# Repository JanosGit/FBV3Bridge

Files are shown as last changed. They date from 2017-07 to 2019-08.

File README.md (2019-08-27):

# FBV3Bridge
PJRC Teensy 3.2 based device to interface a Line 6 FBV3 to a USB-Serial Port to access its functionality through Max for Live or Max/MSP

Inspired by some other projects out there ([this one by rasmartins](https://github.com/rasmartins/fbv2kpa) and [this one by wrbi](https://github.com/wrbi/FBV2MIDI)), that have successfully interfaced the older FBV-range boards, the goal of this project is to make use of the extended functionality of the FBV3 Board - most of all the RGB-LEDs.

Within this project, I'm responsible of designing the hardware that acts as bridge between your PC or Mac and ther Line 6 FBV3 Board. Most of the reverse engineering of the communication protocol and the design of an upcoming Max for Live device that lets you control Ableton Live with an FBV3 board is done by [Soundmanufacture](http://soundmanufacture.net/index.html).

## The Max Patcher

You'll find a first proof-of-cocept Max patcher that allows setting the colours of nearly all Button LEDs as well as reading the state of the buttons and the expression pedal in the "Max" subfolder of this repository.

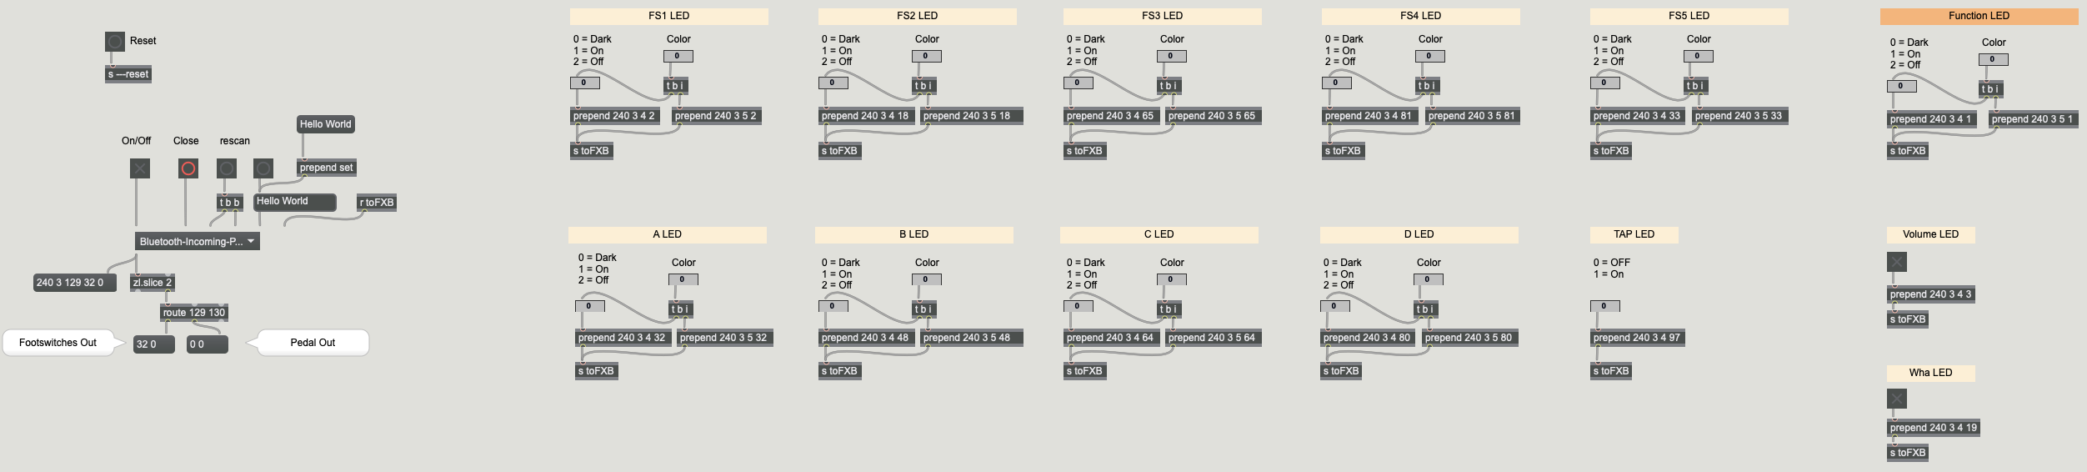
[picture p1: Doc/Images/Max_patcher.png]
Max screenshot

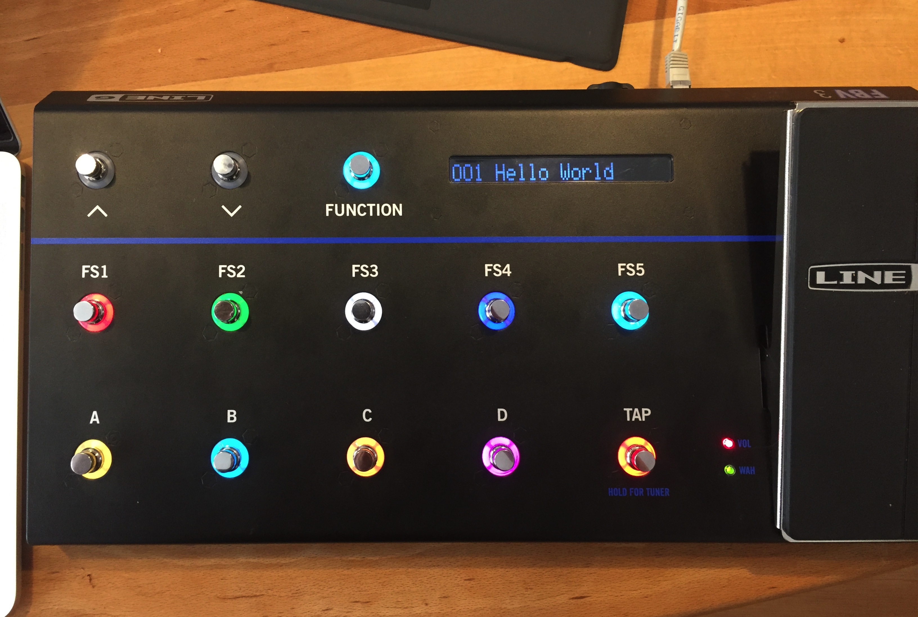
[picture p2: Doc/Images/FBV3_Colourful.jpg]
FBV3 with colourful buttons set by the patch


## The hardware

Our first hardware prototype consists of a small PCB, interfacing two RS485 over RJ45 connections used by Line 6 to the Teensy on the one side and supplying an USB connection to connect with your computer on the other side. The two RJ45 connections were added to make it possible to attach the device between the floorboard and an original Line 6 amp and reord data traffic to make protocol reverse engineering possible. In a second mode of operation the device just initializes the FBV3 board as the amp would do and then acts as a transparent RS485 to serial bridge. 

The initial plan was to power the board via USB, however it seems that not all USB port supply enough current, so we had to modify the design to power it with an external 9V power adapter.

### Next hardware generation

After being successful in reverse-engineering the protocol we are currently planing a second hardware generation. Features of this new hardware should be

- More compact design, all components including the MCU and a proper power suply circuit on one board instead of plugging a Teensy onto the board
- Professional manufactured PCB instead of the home-made design of the prototype, making solering SMT components much easier
- 3D printed housing to make it finally suitable for stage-use
- Fix some minor errors in the schematics

News regarding the new designs will be posted here as soon as available

### Impressions of the prototype

Here are some pictures of the first version of the prototype that was still USB-Bus powered. You'll find the schematics in the "Hardware" subfolder of this repo.

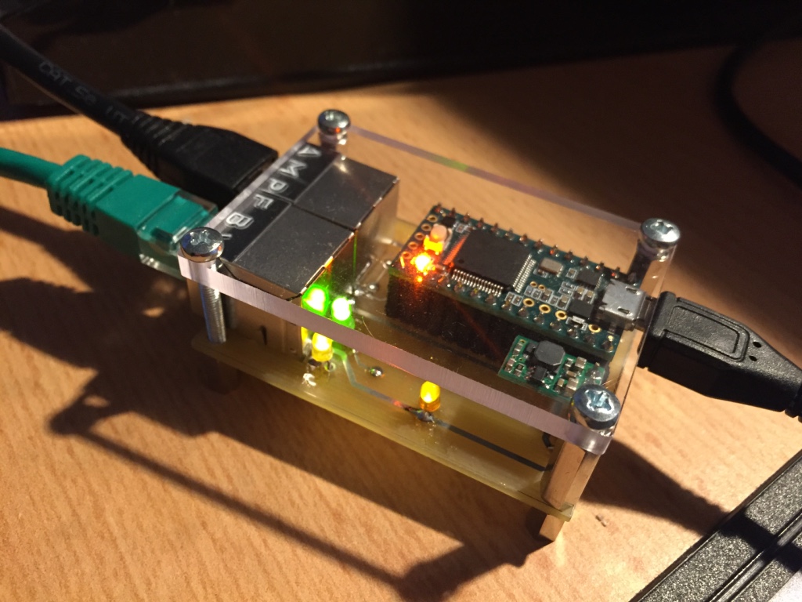
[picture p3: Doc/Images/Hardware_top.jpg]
Hardware top view


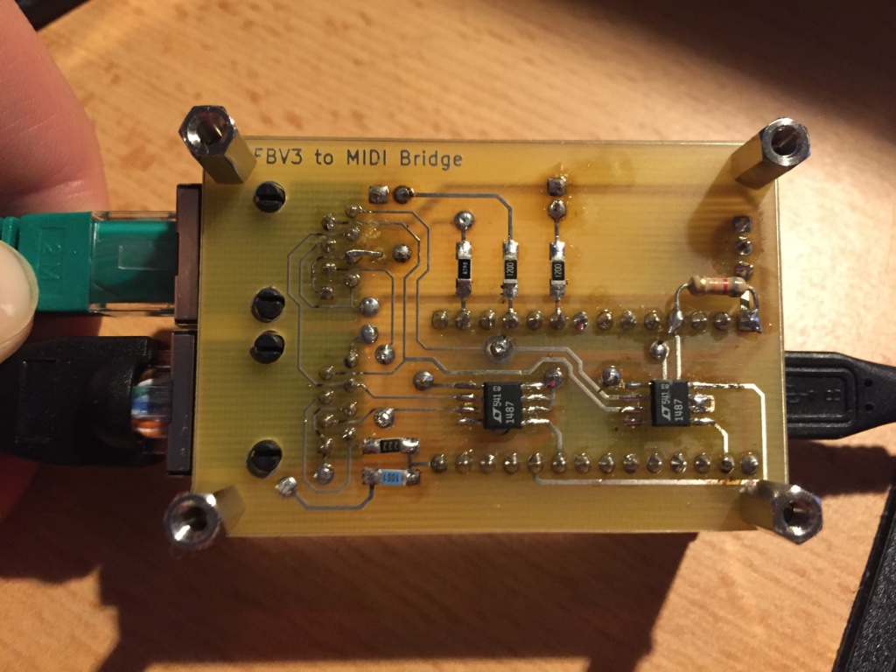
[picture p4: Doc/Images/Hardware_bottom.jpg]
Hardware bottom view


### The software modes of the prototype
As said above, the software for the Teensy has two modes of operation: If both an amp and an FBV3 Board are plugged in, it logs the communication between the two endpoints and prints it in human-readable form to the USB-Serial output. If no amp is plugged in, it sends the same initialization-sequence an amp would send to the FBV3 board and redirects the in/out data streams byte-transparent to the USB-Serial port afterwards.

With the help of the first mode, the protocol of the FBV3 could be reverse-engineered.
Here you see a screenshot of the serial communication logged while the device was in the first mode.

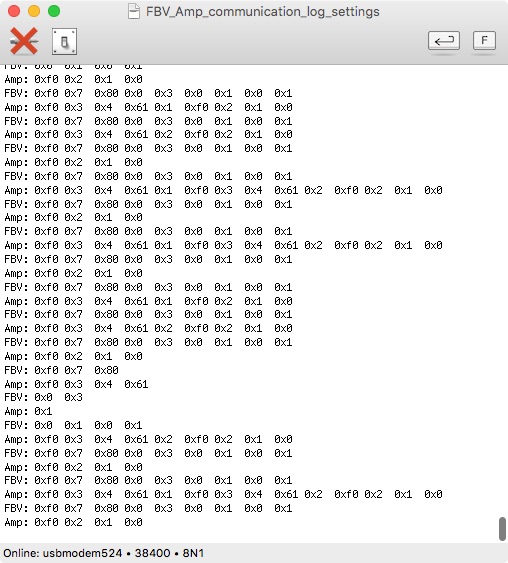
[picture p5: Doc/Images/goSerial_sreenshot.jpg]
goSerial screenshot goSerial Screenshot


In this mode, the amp and the FBV3 behave just like there wouldn't be anything more than a cable connecting them.
In the second mode, the Teensy sends an initialization sequence (actually, completely the same sequence as the Line 6 Spider Amp I had here sent - I just changed the content sent to the LCD display). So it boots up like this:

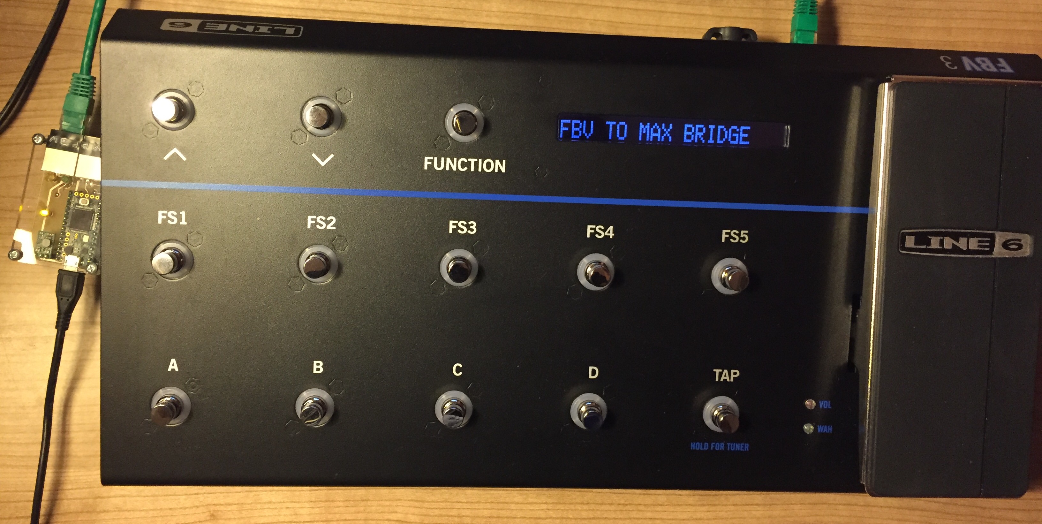
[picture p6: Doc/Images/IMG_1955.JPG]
Teensy initialized the FBV3


The current software is based on the Teensyduino environment and can be found in the "Software/FBV3Bridge" subfolder of this repository

## Known facts about the protocol

Each valid message seems to have the following structure:

| Start byte | Number of bytes following | Command type | Parameters |
|:---:|---|---|---|
| 0xF0 | Counted without this byte --> Message Length - 2 | e.g. 0x04 for Button LEDs | e.g. Button Number, On/Off |

These messages could already be identified:
### Switching Button LEDs

| 0xF0 | 0x03 | 0x04 | Button Number | 0x01 for "On", 0x00 for "Dark" (or "Off" if LED red), 0x02 for "Off" |
|:----:|:----:|:----:|:---:|:---:|

### Setting Button LED Colours

| 0xF0 | 0x03 | 0x05 | Button Number | A value betweem 0x00 and 0x09 for 9 different colours |
|:----:|:----:|:----:|:---:|:---:|

### First three display characters (-> The preset number)
Note: Although Line 6 uses this for the preset number, all possible ascii characters seem to be working here

| 0xF0 | 0x05 | 0x08 | 0x20 | character 1 | character 2 | character 3 |
|:----:|:----:|:----:|:----:|:---:|:---:|:---:|

### The remaining display text
Note: It seems to be unavoidable that there is a whitespace between the first three characters of the preset nubmer and the remainig display text

| 0xF0 | text length + 3 | 0x10 | 0x00 | 0x01 | the text as ascii string |
|:----:|:---:|:----:|:----:|:----:|:---:|

Note that

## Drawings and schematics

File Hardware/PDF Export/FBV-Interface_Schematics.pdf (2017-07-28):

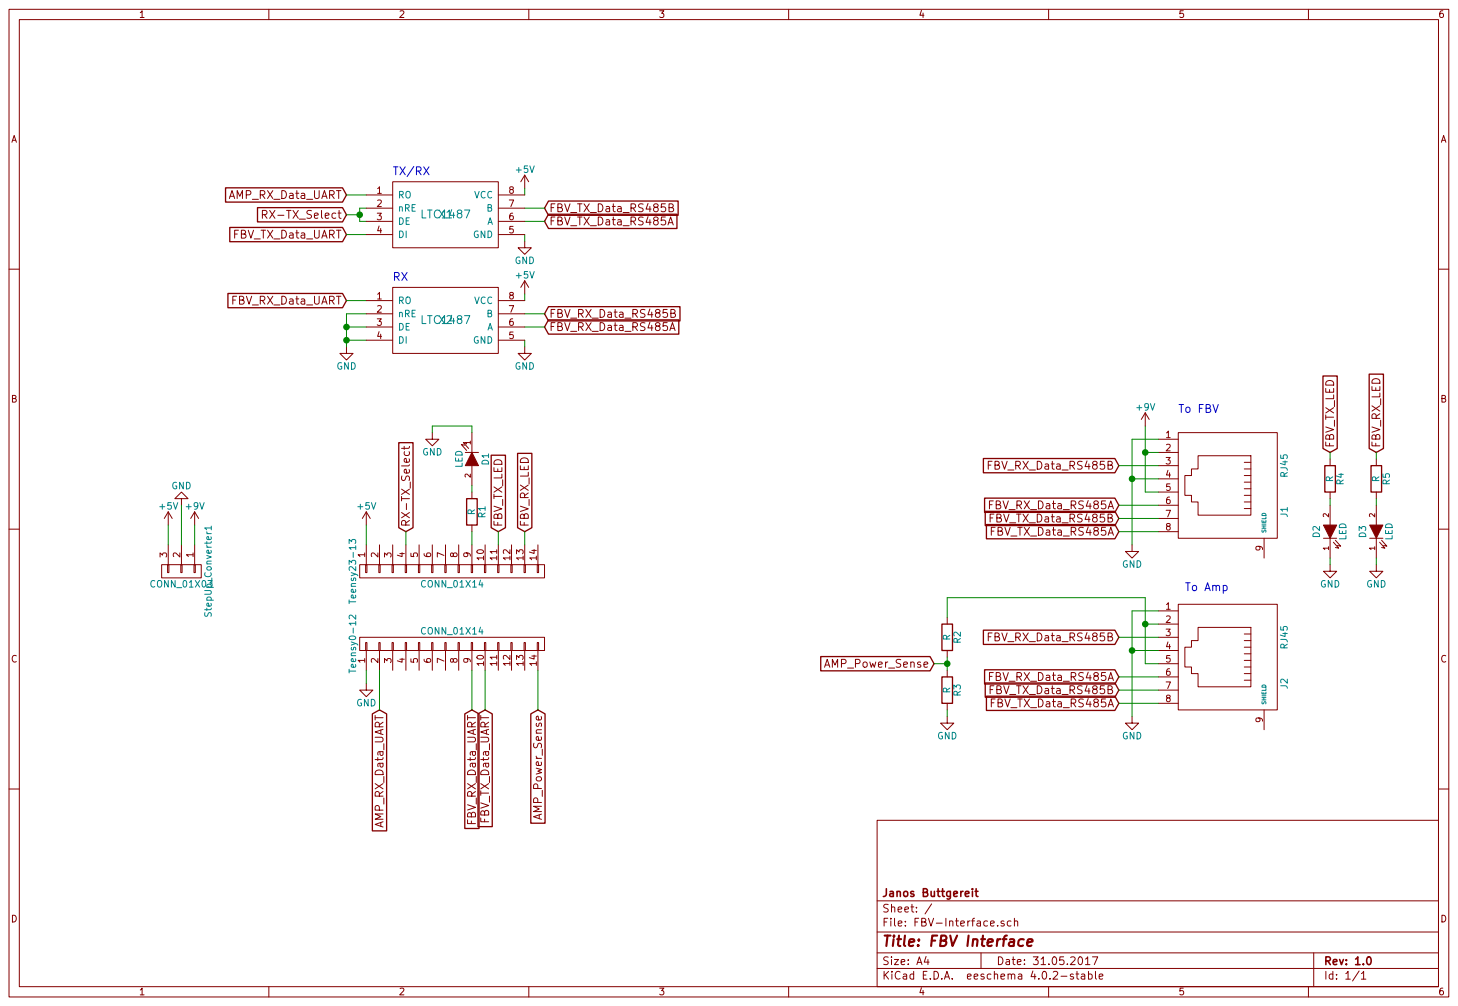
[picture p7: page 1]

1 StepUp_Converter1 CONN_01X03 +5V +9V GND GND RX-TX_Select RO 1

File: FBV-Interface.sch Sheet: / Janos Buttgereit

Id: 1/1 Title: FBV Interface

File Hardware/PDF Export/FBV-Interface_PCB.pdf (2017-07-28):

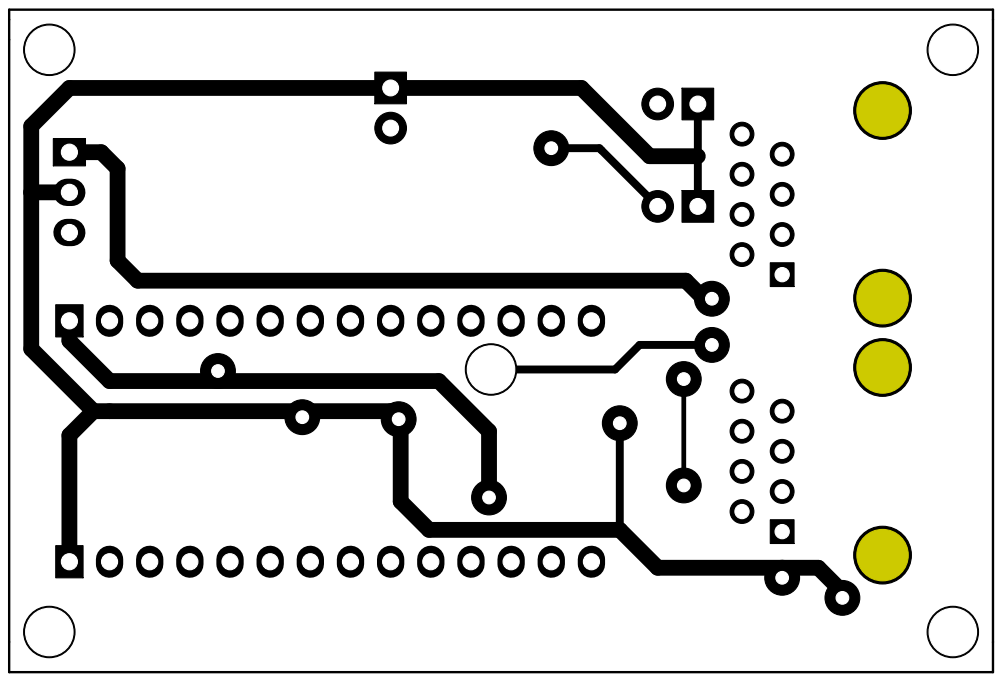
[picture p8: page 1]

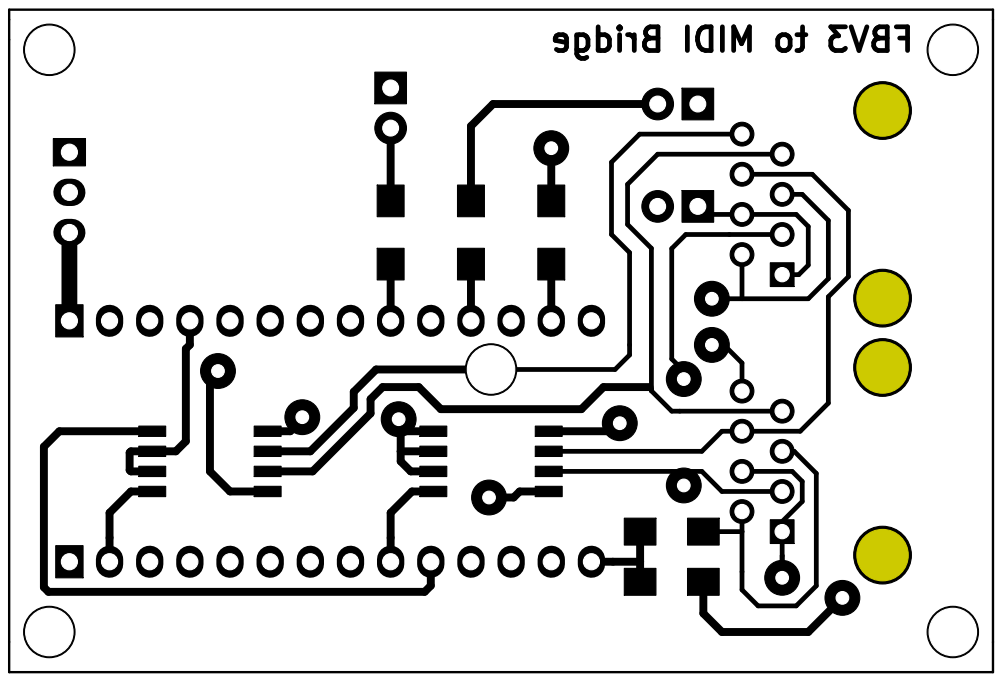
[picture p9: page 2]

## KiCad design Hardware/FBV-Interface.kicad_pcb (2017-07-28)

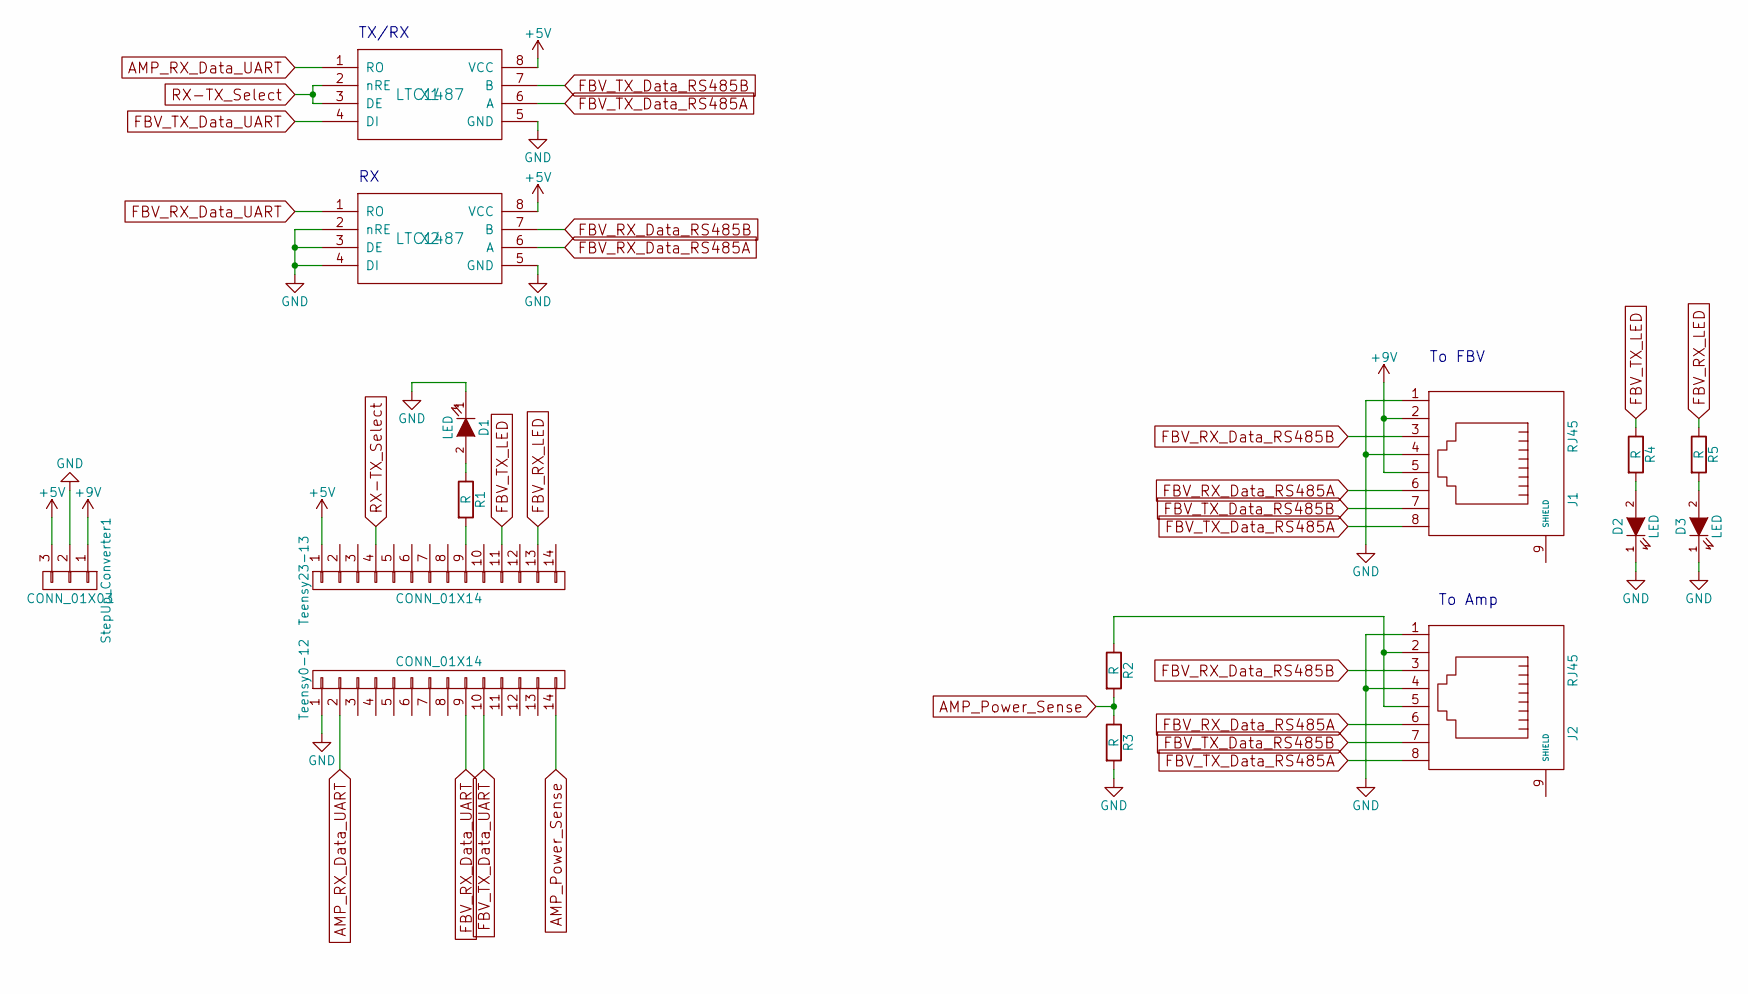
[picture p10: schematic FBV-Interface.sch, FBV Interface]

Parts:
D1, D2, D3: LED; LED-3MM
J1, J2: RJ45; RJ45_8
R1, R2, R3, R4, R5: R; R_1206_HandSoldering
StepUp_Converter1: CONN_01X03; Pin_Header_Straight_1x03
Teensy0-12, Teensy23-13: CONN_01X14; Pin_Header_Straight_1x14
X1, X2: LTC1487

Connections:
+5V: StepUp_Converter1.3, Teensy23-13.1, X1.8 (VCC), X2.8 (VCC)
+9V: J1.2, J1.5, StepUp_Converter1.1
AMP_Power_Sense: R2.2, R3.1, Teensy0-12.14
AMP_RX_Data_UART: Teensy0-12.2, X1.1 (RO)
FBV_RX_Data_RS485A: J1.6, J2.6, X2.6 (A)
FBV_RX_Data_RS485B: J1.3, J2.3, X2.7 (B)
FBV_RX_Data_UART: Teensy0-12.9, X2.1 (RO)
FBV_RX_LED: R5.1, Teensy23-13.13
FBV_TX_Data_RS485A: J1.8, J2.8, X1.6 (A)
FBV_TX_Data_RS485B: J1.7, J2.7, X1.7 (B)
FBV_TX_Data_UART: Teensy0-12.10, X1.4 (DI)
FBV_TX_LED: R4.1, Teensy23-13.11
GND: D1.1 (K), D2.1 (K), D3.1 (K), J1.1, J1.4, J2.1, J2.4, R3.2, StepUp_Converter1.2, Teensy0-12.1, X1.5 (GND), X2.2 (nRE), X2.3 (DE), X2.4 (DI), X2.5 (GND)
unnamed: D1.2 (A), R1.1
unnamed: D2.2 (A), R4.2
unnamed: D3.2 (A), R5.2
unnamed: J2.2, J2.5, R2.1
unnamed: R1.2, Teensy23-13.9
RX-TX_Select: Teensy23-13.4, X1.2 (nRE), X1.3 (DE)

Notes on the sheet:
To FBV
TX/RX
To Amp

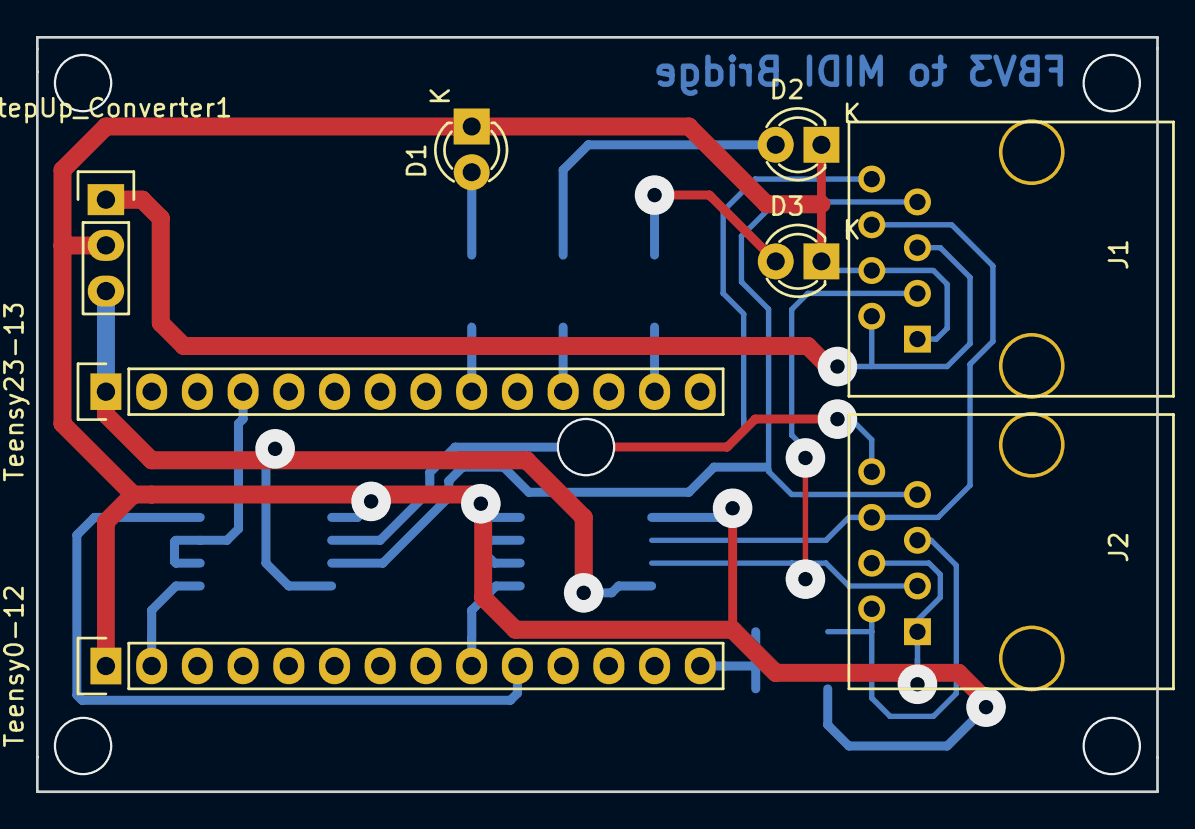
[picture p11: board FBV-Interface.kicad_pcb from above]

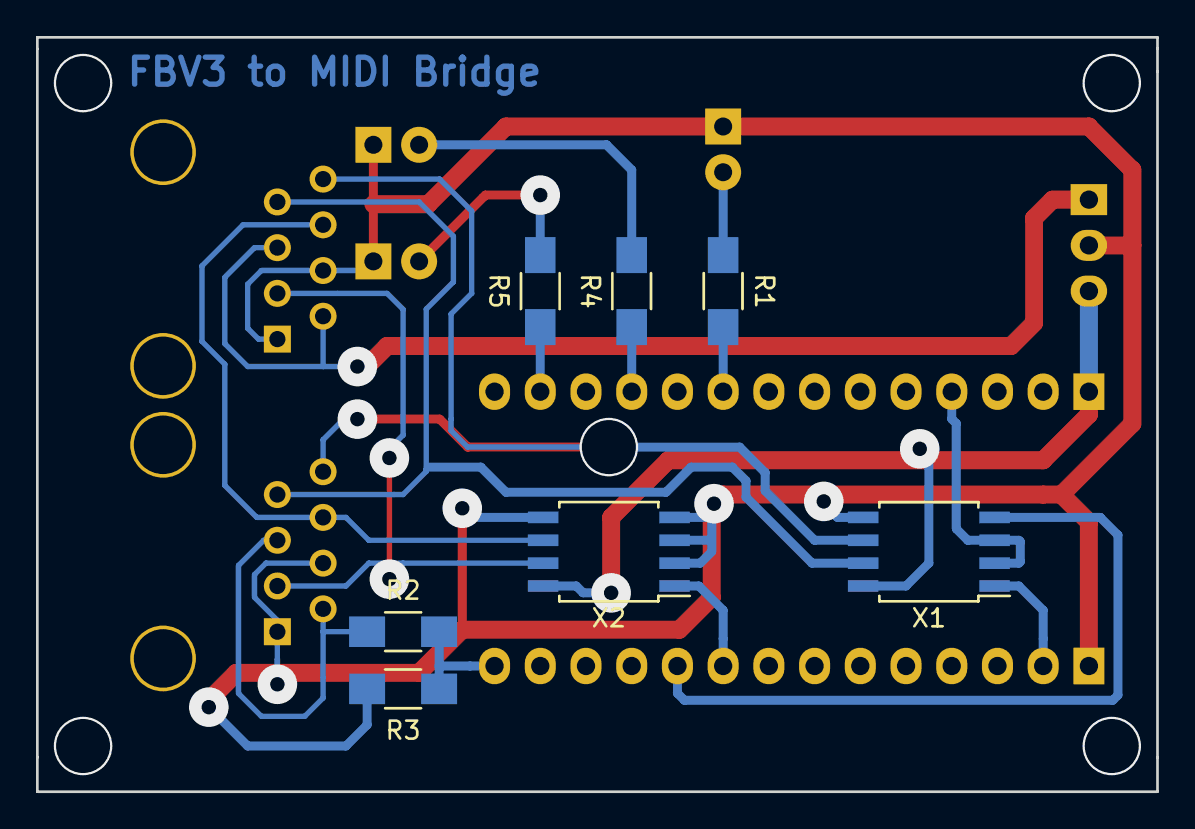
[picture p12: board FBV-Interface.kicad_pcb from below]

Board: 2 copper layers, 62.2 x 41.9 mm, 15 parts (7 on the bottom side), 19 nets.

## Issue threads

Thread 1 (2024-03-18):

How to get a device

JesseWebDotCom, 2024-03-18:
I'm looking for a device that allows my Windows 11 PC to control the FBV 3 (set screen text, enable/disable foot switch LED's, change LED colors, etc.  Does your device enable this and how can I obtain one?

Thanks

JanosGit, 2024-03-18:
Hi,

First of all: I haven't worked on this project for a long time, I built the prototype described here for Tim from https://www.soundmanufacture.net to enable him working on the Max based software side.

This repository contains all the information on how to build one yourself, e.g. the schematics for the hardware and the source code for the software. So you needed to create a PCB (either etch it at home or order it from some PCB manufacturer), get the components, solder them together according to the schematics and program the microcontroller with the software found here. As described in the Readme, I needed to modify the power supply circuit later because it turned out that the USB bus power approach didn't work in all situations.

Long story short: This is a project for people that know their way round with building electronics and software on themselves. If the files found here are not self-explaining and you don't have any experience in that field, this project will probably be not right for you. This is also no final product but a prototype, so expect that you probably need to modify hardware and software yourself to get this thing into a state where it can do whatever you need.

I hope that helps you a bit :)

JesseWebDotCom, 2024-03-18:
Thank you for you quick and full reply. Can I get your thoughts on what I think is a much easier way to do what your project does (that maybe wasn’t available at the time and might help others looking at this GitHub repo for a similar solution):

1) build the hardware from this project: https://github.com/kempline/open_fbv
2) use the software from this project:
https://github.com/kquann/FBV_MIDI

You’ll still need a host to run the “software” (I’ll be running it on a usb connected windows 12 tablet). I plan to build/test this in a week or so when all the parts come in.  If it works out, I’ll document this in a repo and reply with the link.  Just wanted to hear your early thoughts on if this approach sounds right.

thanks again

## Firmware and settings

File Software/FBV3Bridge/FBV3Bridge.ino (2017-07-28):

// ====================== Preprocessor macros =========================

// The serial ports to which the FBV and AMP Inputs are connected
#define FBV_INTERFACE Serial3
#define AMP_INTERFACE Serial1

// Some LEDs
#define POWER_LED 18
#define RX_LED 14
#define TX_LED 16
#define AMP_CONNECTED_LED 13

// Other Pins
#define AMP_POWER_SENSE_PIN 12
#define RX_TX_MODE_PIN 23


// ======================== enums =====================================
typedef enum {
  listenToAmp = 0,
  sendToFBV = 1
} RxTxMode;

typedef enum {
  disconnected = 0,
  connected = 1
} AmpConnectionState;

typedef enum {
  amp,
  fbv
} LastBytesCameFrom;


// ============================ Global Variables =========================

// Needed to determine the state of operation
RxTxMode rxTxMode = listenToAmp;
AmpConnectionState ampConnectionState = connected;
bool startupSequenceShouldBeSent = true;

// Needed to handle send & receive operations
LastBytesCameFrom lastBytesCameFrom = fbv;
// These char buffers hold incomming data in listenToAmp mode. Both always 
// contain the prefix "Amp: " or "FBV: ". For easier access, the pointers
// ampDataBuffer and fbvDataBuffer always point to the 4th buffer field, 
// where the first chars should be placed
const uint8_t dataBuffersMaxCapacity = 251;
char ampDataBufferWithPrefix[256];
char fbvDataBufferWithPrefix[256];
char *ampDataBuffer;
char *fbvDataBuffer;

uint8_t ampDataBufferFilledUntil = 0;
uint8_t fbvDataBufferFilledUntil = 0;

// This will be the time that has to pass with nothing happening on the line until the received data will be sent automatically
const uint64_t sendTimeout = 400;
uint64_t sentLastAmpDataBuffer;
uint64_t sentLastFbvDataBuffer;

// =========================== Timers for RX/TX LEDs =======================================

IntervalTimer rxLEDTimer;
IntervalTimer txLEDTimer;
volatile bool switchOnRxLED = false;
volatile bool rxLEDWasSwitchedOn = false;
volatile bool switchOnTxLED = false;
volatile bool txLEDWasSwitchedOn = false;

// =========================== Forward declarations ========================================
void doListenAndPrintWork();

void serialBridgeModeStartupSequence();

void doSerialBridgeWork();

void appendByteToBuffer (char *buffer, uint8_t &bufferFilledUntil, char byteReceived);

void rxLED_ISR();
void txLED_ISR();

AmpConnectionState getAmpConnectionState();

void waitForSequence (HardwareSerial &interface, const char *sequence, uint8_t sequenceLength);

void pinDisable(const uint8_t pin);




void setup() {
    
  // Setup UART Interfaces (Polarity changed due to unintentionally swapped differential pins on the pcb)
  FBV_INTERFACE.begin (32150, SERIAL_8N1_RXINV_TXINV);
  //FBV_INTERFACE.begin (32150);
  AMP_INTERFACE.begin (32150, SERIAL_8N1_RXINV_TXINV);
  
  // Setup all IO-Connections
  pinMode (POWER_LED, OUTPUT);
  pinMode (RX_LED, OUTPUT);
  pinMode (TX_LED, OUTPUT);
  pinMode (AMP_CONNECTED_LED, OUTPUT);
  pinMode (AMP_POWER_SENSE_PIN, INPUT);
  pinMode (RX_TX_MODE_PIN, OUTPUT);

  // Set default output pin values
  digitalWrite (RX_TX_MODE_PIN, rxTxMode);
  digitalWrite (POWER_LED, HIGH);
  digitalWrite (AMP_CONNECTED_LED, LOW);
  digitalWrite (RX_LED, LOW);
  digitalWrite (TX_LED, LOW);

  // Fill the Data Buffers with the default prefixes
  strcpy (ampDataBufferWithPrefix, "Amp:\n");
  strcpy (fbvDataBufferWithPrefix, "FBV:\n");
  ampDataBuffer = &ampDataBufferWithPrefix[4];
  fbvDataBuffer = &fbvDataBufferWithPrefix[4];

  // start the led interrupts
  rxLEDTimer.begin (rxLED_ISR, 50000);
  txLEDTimer.begin (txLED_ISR, 50000);
  rxLEDTimer.priority (254);
  txLEDTimer.priority (254);

  // Set the timeout-variables
  sentLastAmpDataBuffer = millis();
  sentLastFbvDataBuffer = sentLastAmpDataBuffer;

  Serial.println ("FBV3 to MIDI Bridge booted");
}

void loop() {

  // check if an amp is detected
  ampConnectionState = getAmpConnectionState();

  // depending on the amp connection state, chose the right mode of operation
  if (ampConnectionState == connected) {
    // Just listen and print.
    rxTxMode = listenToAmp;
    pinMode (RX_TX_MODE_PIN, OUTPUT);
    digitalWrite (RX_TX_MODE_PIN, rxTxMode);
    doListenAndPrintWork();
  }

  else {
    // Act as Serial Bridge
    rxTxMode = sendToFBV;
    pinDisable (RX_TX_MODE_PIN);
    
    if (startupSequenceShouldBeSent) {
      // this will only happen once
      serialBridgeModeStartupSequence();
    }
    else {
      doSerialBridgeWork();
    }
  }
}


/** This is the main work done when in "listen to amp"-Mode. It will check if any data arrived. If there is already some
    data from the same sender (FBV or amp) that sent data in the last call to this function it will be appended to the data buffer.
    If the opposite sender also sent some data, the buffer is sent out via USB Serial in text representation. This way the user
    may notice how both ends exchange their messages.
    
    If there is no more communication over a specified timeout value, the remainig unsent buffer conten (if there is any) will be
    sent automatically and will become flagged with "timeout" at the end of the string.
 */
void doListenAndPrintWork() {
  // Who sent some data?
  const int bytesAvailableFromFBV = FBV_INTERFACE.available();
  const int bytesAvailableFromAmp = AMP_INTERFACE.available();

  if (lastBytesCameFrom == amp) {
    // check if there are even more bytes from the amp
    if (bytesAvailableFromAmp > 0) {
     switchOnTxLED = true;
     // read everything to the buffer
     for (int i = 0; i < bytesAvailableFromAmp; i++) {
       const char tempByte = AMP_INTERFACE.read();
       appendByteToBuffer (ampDataBuffer, ampDataBufferFilledUntil, tempByte);
     }
    }


    // check if there are also some bytes from the fbv 
    if (bytesAvailableFromFBV > 0) {
      lastBytesCameFrom = fbv;
      // send the amp buffer if there is any data in it
      if (ampDataBufferFilledUntil > 0) {
        Serial.write (ampDataBufferWithPrefix);
        sentLastAmpDataBuffer = millis();
        ampDataBufferFilledUntil = 0;
      }

      // now read fbv bytes to the fbv buffer
      switchOnRxLED = true;
      for (int i = 0; i < bytesAvailableFromFBV; i++) {
        const char tempByte = FBV_INTERFACE.read();
        appendByteToBuffer (fbvDataBuffer, fbvDataBufferFilledUntil, tempByte);
      }
    }



    // flush the buffer in case of timeout or a full buffer
    const uint8_t spaceRemainingInBuffer = dataBuffersMaxCapacity - ampDataBufferFilledUntil;
    const uint64_t timeUntilLastSending = millis() - sentLastAmpDataBuffer;
    if ((spaceRemainingInBuffer < 6) || ((timeUntilLastSending > sendTimeout) && (ampDataBufferFilledUntil > 0))) {
      if (timeUntilLastSending > sendTimeout) {
        strcpy(&fbvDataBuffer[fbvDataBufferFilledUntil], " - timeout\n");
      }
      Serial.write (ampDataBufferWithPrefix);
      sentLastAmpDataBuffer = millis();
      ampDataBufferFilledUntil = 0;
    }
  }

  else { // lastBytesCameFrom == fbv
    // check if there are even more bytes from the fbv
    if (bytesAvailableFromFBV > 0) {
      // read everything to the buffer
      switchOnRxLED = true;
      for (int i = 0; i < bytesAvailableFromFBV; i++) {
        const char tempByte = FBV_INTERFACE.read();
        appendByteToBuffer (fbvDataBuffer, fbvDataBufferFilledUntil, tempByte);
      }
    }

    // check if there are also some bytes from the amp
    if (bytesAvailableFromAmp > 0) {
      lastBytesCameFrom = amp;
      // send the fbv buffer if there is any data in it
      if (fbvDataBufferFilledUntil > 0) {
        Serial.write (fbvDataBufferWithPrefix);
        sentLastFbvDataBuffer = millis();
        fbvDataBufferFilledUntil = 0;
      }

      // now read amp bytes to the amp buffer
      switchOnTxLED = true;
      for (int i = 0; i < bytesAvailableFromAmp; i++) {
        const char tempByte = AMP_INTERFACE.read();
        appendByteToBuffer (ampDataBuffer, ampDataBufferFilledUntil, tempByte);
      }
    }


    // flush the buffer in case of timeout or a full buffer
    const uint8_t spaceRemainingInBuffer = dataBuffersMaxCapacity - fbvDataBufferFilledUntil;
    const uint64_t timeUntilLastSending = millis() - sentLastFbvDataBuffer;
    if ((spaceRemainingInBuffer < 12) || ((timeUntilLastSending > sendTimeout) && (fbvDataBufferFilledUntil > 0))) {
      if (timeUntilLastSending > sendTimeout) {
        strcpy(&fbvDataBuffer[fbvDataBufferFilledUntil], " - timeout\n");
      }
      Serial.write (fbvDataBufferWithPrefix);
      sentLastFbvDataBuffer = millis();
      fbvDataBufferFilledUntil = 0;
    }
  }
}



/** Only called once. If no amp is detected, this sequence will imitate the startup sequence normally done
    between a Line 6 Amp and the FBV3. Except for the display strings, this one is the result of pure try &
    error work.
 */
void serialBridgeModeStartupSequence() {
  Serial.println ("No Amp detected, chosing serial bridge mode. Waiting for FBV3 to connect");

  const char seq1[4] = {0xF0, 0x02, 0x90, 0x01};
  waitForSequence (FBV_INTERFACE, seq1, sizeof (seq1));
  
  switchOnTxLED = true;
  const char ans1[4] = {0xF0, 0x02, 0x50, 0x00};
  FBV_INTERFACE.write (ans1, sizeof (ans1));

  const char seq2_1[4] = {0xF0, 0x02, 0x90, 0x00};
  waitForSequence (FBV_INTERFACE, seq2_1, sizeof (seq2_1));
  
  const char seq2_2[4] = {0xF0, 0x02, 0x30, 0x08};
  waitForSequence (FBV_INTERFACE, seq2_2, sizeof (seq2_2));
  
  switchOnTxLED = true;
  const char ans2_1[3] = {0xF0, 0x01, 0x40};
  FBV_INTERFACE.write (ans2_1, sizeof (ans2_1));

  switchOnTxLED = true;
  const char ans2_2[5] = {0xF0, 0x03, 0x31, 0x01, 0x16};
  FBV_INTERFACE.write (ans2_2, sizeof (ans2_2));


  const char setPresetDisplayText[7] = {0XF0, 0x05, 0x08, 0x20, 'F', 'B',  'V'};
  FBV_INTERFACE.write (setPresetDisplayText, sizeof (setPresetDisplayText));
  
  const char setMainDisplayText[18] = {0xF0, 16, 0x10, 0x00, 0x01, 'T', 'O', ' ', 'M', 'A', 'X', ' ', 'B', 'R', 'I', 'D', 'G', 'E'};
  FBV_INTERFACE.write (setMainDisplayText, sizeof (setMainDisplayText));

  
  switchOnTxLED = true;
  const char ans3[5] = {0xf0, 0x03,  0x05,  0x20, 0x02};
  FBV_INTERFACE.write (ans3, sizeof (ans3));

  const char ans4[4] = {0xf0, 0x2,  0x1,  0x0};
  FBV_INTERFACE.write (ans4, sizeof (ans4));
      
  Serial.println ("Connected to FBV3");

  // this sequence will only be sent once
  startupSequenceShouldBeSent = false;
}


/** This is the main work done when in serial bridge mode. It just passes everything it receives from the fbv to
    the usb serial port and vice versa.
 */
void doSerialBridgeWork() {
  const int bytesAvailableFromFBV = FBV_INTERFACE.available();
  
      for (int i = 0; i < bytesAvailableFromFBV; i++) {
        switchOnRxLED = true;
        const uint8_t lastByte = FBV_INTERFACE.read();
        Serial.write(lastByte);
      }
      
      const int bytesAvailableFromSerial = Serial.available();

      for (int i = 0; i < bytesAvailableFromSerial; i++){
        switchOnTxLED = true;
        const char tmp = Serial.read();
        FBV_INTERFACE.write(tmp);
      }
}

/** Appends the byte received as a hex formatted value to the string buffer*/
void appendByteToBuffer (char *buffer, uint8_t &bufferFilledUntil, char byteReceived) {

  const uint8_t spaceRemainingInBuffer = dataBuffersMaxCapacity - bufferFilledUntil;

  if (spaceRemainingInBuffer > 6) {
    sprintf (&buffer[bufferFilledUntil], " 0x%x \n", (uint8_t)byteReceived);
    bufferFilledUntil += 5;
  }
  
}

/** Returns if an amp was detected and switches the connection LED on or off */
inline AmpConnectionState getAmpConnectionState() {
  const bool cs = digitalRead (AMP_POWER_SENSE_PIN);
  digitalWrite (AMP_CONNECTED_LED, cs);
  return (AmpConnectionState)cs;
}



/** Kind of a state machine waiting for a specific sequence to be received.
    Returns when the sequence was received */
void waitForSequence (HardwareSerial &interface, const char *sequence, uint8_t sequenceLength) {

  int i = 0;

  while (i < sequenceLength) {
    const char lastByte = interface.read();
    if (lastByte != 0xFF) {
      switchOnRxLED = true;
      if (lastByte == sequence[i]) {
        i++;
      }
      else {
        i = 0;
      }
    }
  }
}


/** Sets a pin to tristate status. This allows to connect a 5V Pullup-Resistor to the pin. */
void pinDisable(const uint8_t pin) {
  volatile uint32_t *config;  
  if (pin >= CORE_NUM_TOTAL_PINS) return;
  config = portConfigRegister(pin);
  *config = 0;
}

/** Interrupt service routine to handle the blinking RX LED. This was solved this way to let the led
    light up a few miliseconds longer then the actual receive-operation takes place to make it visible.
 */
void rxLED_ISR() {
  if (switchOnRxLED) {
    digitalWrite (RX_LED, HIGH);
    rxLEDWasSwitchedOn = true;
    switchOnRxLED = false;
  }
  else if (rxLEDWasSwitchedOn) {
    digitalWrite (RX_LED, LOW);
    rxLEDWasSwitchedOn = false;
  }
}


/** Interrupt service routine to handle the blinking TX LED. This was solved this way to let the led
    light up a few miliseconds longer then the actual receive-operation takes place to make it visible.
 */
void txLED_ISR() {
  if (switchOnTxLED) {
    digitalWrite (TX_LED, HIGH);
    txLEDWasSwitchedOn = true;
    switchOnTxLED = false;
  }
  else if (txLEDWasSwitchedOn) {
    digitalWrite (TX_LED, LOW);
    txLEDWasSwitchedOn = false;
  }
}
